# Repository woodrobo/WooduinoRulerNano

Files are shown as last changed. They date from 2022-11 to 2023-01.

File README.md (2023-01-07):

# WooduinoRulerNano
WooduinoRulerNanoは定規風Arduino Nano互換機です。  
定規っぽい見た目なだけでなく、電源電流マシマシに設計していて、3.3Vには800mAの3端子レギュレータを採用していて5Vも配線幅的には2Aほど流せます。Vin端子は使ったこと無かったのでつけていないです。  
[BOOTH](https://woodrobo.booth.pm/items/3751720)で販売しています。

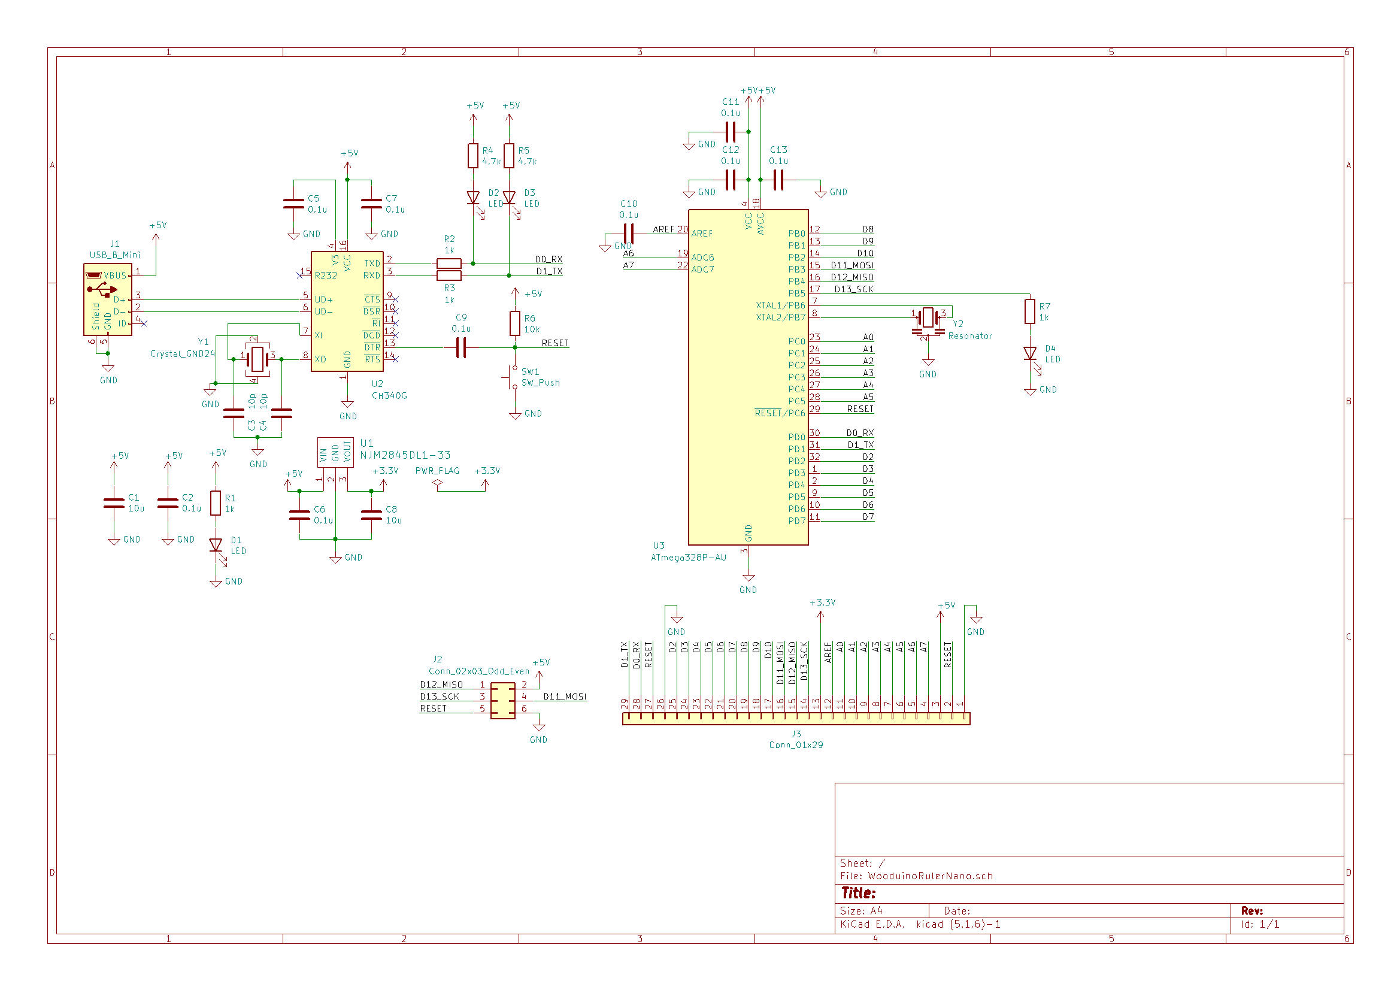
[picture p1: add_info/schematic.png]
  
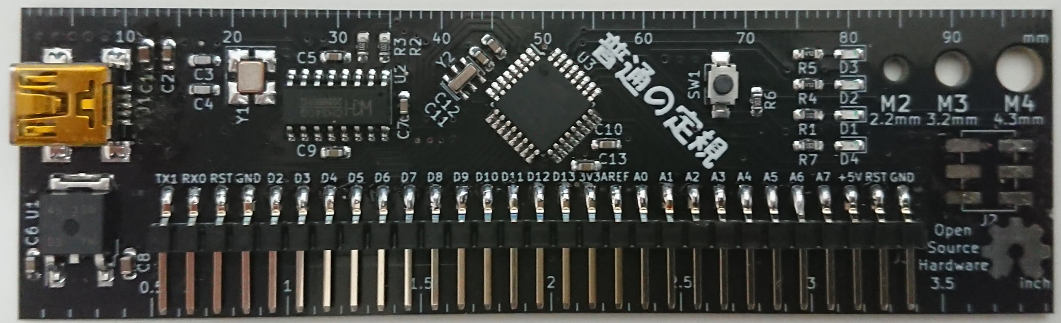
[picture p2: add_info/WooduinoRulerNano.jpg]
基板表面
  
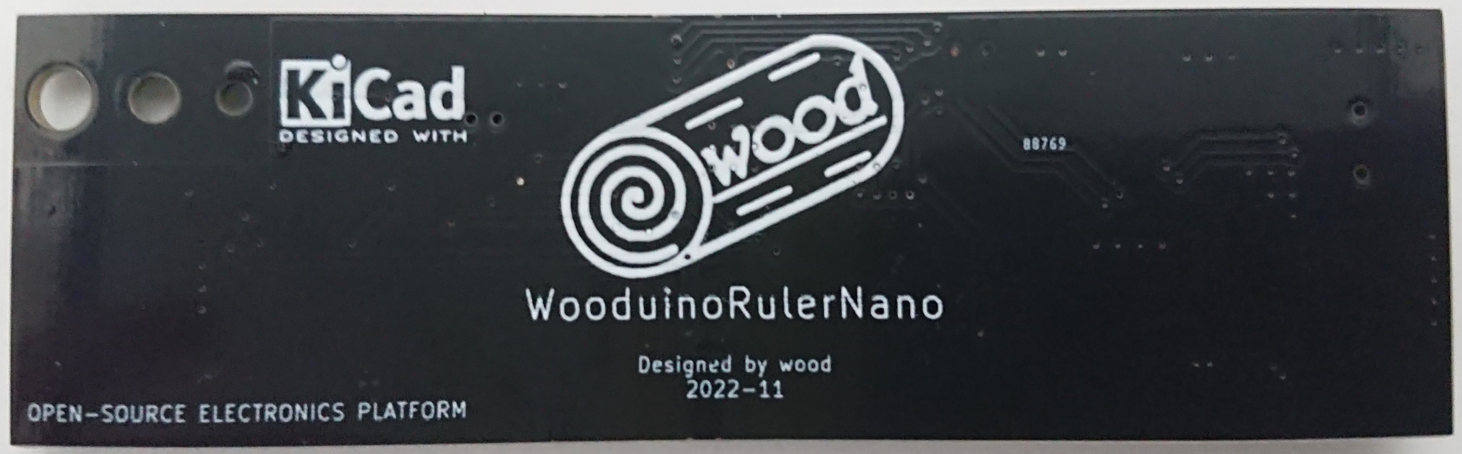
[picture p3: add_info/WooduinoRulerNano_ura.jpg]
基板裏面
  

# 部品・はんだづけについて
add_info/部品表.csvを見てはんだづけを行ってください。  
(ちなみにCH340GではなくCH340Cを使用すればC3,C4,Y1を省略できます)  
向きを間違えやすい4つの箇所を説明します。  

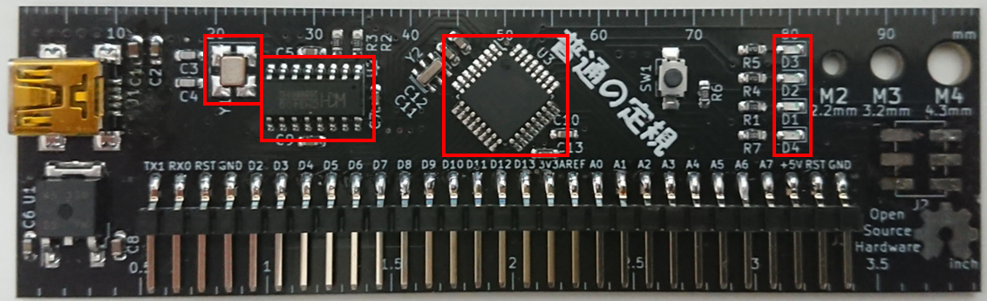
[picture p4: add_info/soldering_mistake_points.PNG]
  

1.クリスタル(12MHz)  
赤枠が1番ピンなので赤枠同士が合うようにしてください。裏面の方が分かりやすいので裏面も写真にのせています。  
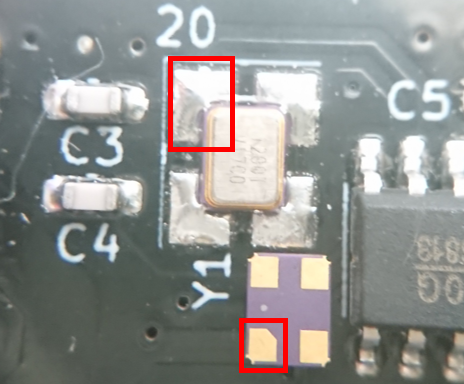
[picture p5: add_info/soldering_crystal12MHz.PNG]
  

2.CH340G  
〇のマークは1番ピンの意味なので、〇のマークに注目して画像と同様の向きにしてください。  
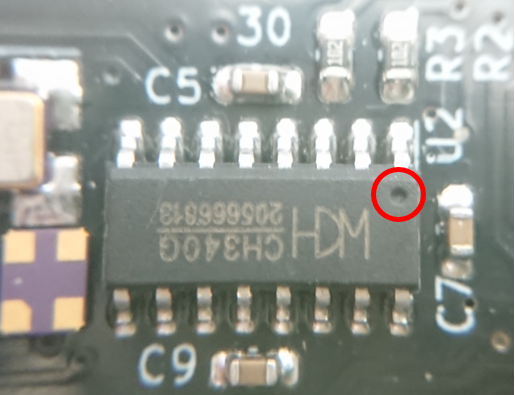
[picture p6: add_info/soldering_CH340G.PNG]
  

3.ATMEGA328P  
〇のマークは1番ピンの意味なので、〇のマークに注目して画像と同様の向きにしてください。  
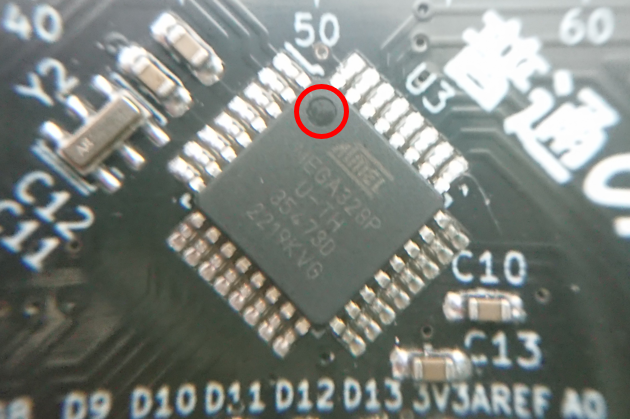
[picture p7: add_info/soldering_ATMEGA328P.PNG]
  

4.LED  
LEDにはアノード・カソードという端子があり極性があります。写真のような向きにしてください。裏面の方が分かりやすいので裏面も写真にのせています。  
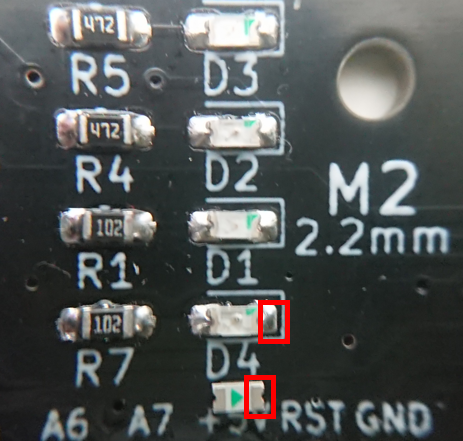
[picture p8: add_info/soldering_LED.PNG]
  

# ブートローダ書き込みについて
Arduinoはブートローダと呼ばれるプログラムを書きこむためのプログラムを書きこむことで動作します。公式の説明は[ここ](https://docs.arduino.cc/built-in-examples/arduino-isp/ArduinoISP)。  
ここではArduino Unoを用いてWooduinoRulerNanoに書きこみを行う方法を説明します。(WooduinoRulerNanoはArduino Nano互換機なのでArduino Nanoについて解説されている他のサイトも参考にしてみてください)  

※Arduino Unoの代わりにArduino Nanoを用いてもやり方は同じです。Arduino UnoのところをArduino Nanoに読み替えてください。 それ以外のArduinoから書き込みを行いたい場合は他のサイトを参照してください。 

**テスト環境**  
ArduinoIDE 1.8.13  
Windows 10

**1.まずはArduino Unoにブートローダ書き込み用のプログラムを書きこみます。**

ファイル->スケッチ例->ArduinoISP->ArduinoISPを開きます。  
Arduino Unoに書きこみます。  

**2.Arduino UnoとWooduinoRulerNanoを結線します。**

書き込みには以下の表に示すように6本の配線が必要です。配線時にはどちらも電源供給は行わないでください。RESETの機能に関しては書き込み機と書き込み対象でピンが違うので注意してください。

|  機能  |  書き込み機(Arduino Uno)  |  WooduinoRulerNano
| ---- | ---- |  ----  |
|  MOSI  |  11  |  11  |
|  MISO  |  12  |  12  |
|  SCK  |  13  |  13  |
|  RESET  |  10  |  RESET  |
|  VCC  |  5V  |  5V  |
|  GND  |  GND  |  GND  |

**3.ブートローダを書きこみます。**

書き込み機であるArduino UnoとパソコンをUSBケーブルで接続してください。(WooduinoRulerNanoへはUSBケーブルを**接続しません**)  

ArduinoIDEにて以下のように設定を行います。

- ツール->ボード->Arduino Nano  
- ツール->プロセッサ->ATmega328P  
- 「ツール->シリアルポート」に書き込み装置のArduino Unoのポートを選択
- ツール->書き込み装置->Arduino as ISP

「ツール->ブートローダを書き込む」でSuccessになれば成功です。

**(4.Lチカのプログラムを書きこんでみましょう。)**  

WooduinoRulerNanoとパソコンをUSBケーブルで接続してください。  

ファイル->スケッチ例->01.Basics->Blinkを開きます。  

- ツール->ボード->Arduino Nano  
- ツール->プロセッサ->ATmega328P 
- 「ツール->シリアルポート」にWooduinoRulerNanoのポートを選択
- ツール->書き込み装置->ArduinoISP

書き込んでLチカができたら成功です。  

# トラブルシューティング
Q.WooduinoRulerNanoのUSBまわりがおかしい  
A.WooduinoRulerNanoのUSBシリアル変換にはCH340を使用しているのでUSBドライバがパソコンにインストールされていない可能性があります。CH340のUSBドライバをパソコンに入れてください。

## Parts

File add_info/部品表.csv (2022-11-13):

Reference | Value | Footprint | 説明
C1 | 10u | Capacitor_SMD:C_0603_1608Metric_Pad1.05x0.95mm_HandSolder | チップコンデンサ10uF
C2 | 0.1u | Capacitor_SMD:C_0603_1608Metric_Pad1.05x0.95mm_HandSolder | チップコンデンサ0.1uF
C3 | 10p | Capacitor_SMD:C_0603_1608Metric_Pad1.05x0.95mm_HandSolder | チップコンデンサ10pF
C4 | 10p | Capacitor_SMD:C_0603_1608Metric_Pad1.05x0.95mm_HandSolder | チップコンデンサ10pF
C5 | 0.1u | Capacitor_SMD:C_0603_1608Metric_Pad1.05x0.95mm_HandSolder | チップコンデンサ0.1uF
C6 | 0.1u | Capacitor_SMD:C_0603_1608Metric_Pad1.05x0.95mm_HandSolder | チップコンデンサ0.1uF
C7 | 0.1u | Capacitor_SMD:C_0603_1608Metric_Pad1.05x0.95mm_HandSolder | チップコンデンサ0.1uF
C8 | 10u | Capacitor_SMD:C_0603_1608Metric_Pad1.05x0.95mm_HandSolder | チップコンデンサ10uF
C9 | 0.1u | Capacitor_SMD:C_0603_1608Metric_Pad1.05x0.95mm_HandSolder | チップコンデンサ0.1uF
C10 | 0.1u | Capacitor_SMD:C_0603_1608Metric_Pad1.05x0.95mm_HandSolder | チップコンデンサ0.1uF
C11 | 0.1u | Capacitor_SMD:C_0603_1608Metric_Pad1.05x0.95mm_HandSolder | チップコンデンサ0.1uF
C12 | 0.1u | Capacitor_SMD:C_0603_1608Metric_Pad1.05x0.95mm_HandSolder | チップコンデンサ0.1uF
C13 | 0.1u | Capacitor_SMD:C_0603_1608Metric_Pad1.05x0.95mm_HandSolder | チップコンデンサ0.1uF
D1 | LED | LED_SMD:LED_0603_1608Metric_Pad1.05x0.95mm_HandSolder | チップLED GREEN
D2 | LED | LED_SMD:LED_0603_1608Metric_Pad1.05x0.95mm_HandSolder | チップLED RED
D3 | LED | LED_SMD:LED_0603_1608Metric_Pad1.05x0.95mm_HandSolder | チップLED GREEN
D4 | LED | LED_SMD:LED_0603_1608Metric_Pad1.05x0.95mm_HandSolder | チップLED YELLOW
J1 | USB_B_Mini | Connector_USB:USB_Mini-B_Wuerth_65100516121_Horizontal | USB miniBコネクタ
J2 | Conn_02x03_Odd_Even | Connector_PinHeader_2.54mm:PinHeader_2x03_P2.54mm_Vertical_SMD | ICSP用PAD はんだづけ非推奨
J3 | Conn_01x29 | 0_kicad_wood:PinHeader_1x29_P2.54mm_Horizontal_SMD_PSL-410256-29 | 表面実装ライトアングルピンヘッダ 1×29
R1 | 1k | Resistor_SMD:R_0603_1608Metric_Pad1.05x0.95mm_HandSolder | チップ抵抗1kΩ
R2 | 1k | Resistor_SMD:R_0603_1608Metric_Pad1.05x0.95mm_HandSolder | チップ抵抗1kΩ
R3 | 1k | Resistor_SMD:R_0603_1608Metric_Pad1.05x0.95mm_HandSolder | チップ抵抗1kΩ
R4 | 4.7k | Resistor_SMD:R_0603_1608Metric_Pad1.05x0.95mm_HandSolder | チップ抵抗4.7kΩ
R5 | 4.7k | Resistor_SMD:R_0603_1608Metric_Pad1.05x0.95mm_HandSolder | チップ抵抗4.7kΩ
R6 | 10k | Resistor_SMD:R_0603_1608Metric_Pad1.05x0.95mm_HandSolder | チップ抵抗10kΩ
R7 | 1k | Resistor_SMD:R_0603_1608Metric_Pad1.05x0.95mm_HandSolder | チップ抵抗1kΩ
SW1 | SW_Push | 0_kicad_wood:SW_TVAF06-A020B-R | 表面実装スイッチ
U1 | NJM2845DL1-33 | Package_TO_SOT_SMD:TO-252-2 | 3端子レギュレータ NJM2845DL1-33
U2 | CH340G | Package_SO:SOIC-16_3.9x9.9mm_P1.27mm | USBシリアル変換 CH340G
U3 | ATmega328P-AU | Package_QFP:TQFP-32_7x7mm_P0.8mm | AVRマイコン ATMEGA328P-AU
Y1 | Crystal_GND24 | Crystal:Crystal_SMD_SeikoEpson_FA238V-4Pin_3.2x2.5mm_HandSoldering | クリスタル12MHz
Y2 | Resonator | Crystal:Resonator_SMD_muRata_CSTxExxV-3Pin_3.0x1.1mm_HandSoldering | セラロック16MHz

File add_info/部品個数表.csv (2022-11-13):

部品名 | 価格 | 個数 | 合計 | URL | 備考
チップコンデンサ10uF | 15 | 2 | 30 | https://akizukidenshi.com/catalog/g/gP-13161/
チップコンデンサ0.1uF | 2.5 | 9 | 22.5 | https://akizukidenshi.com/catalog/g/gP-13374/
チップコンデンサ10pF | 1.8 | 2 | 3.6 | https://akizukidenshi.com/catalog/g/gP-05520/
チップLED GREEN | 12.5 | 2 | 25 | https://akizukidenshi.com/catalog/g/gI-06417/
チップLED RED | 10 | 1 | 10 | https://akizukidenshi.com/catalog/g/gI-03978/
チップLED YELLOW | 10 | 1 | 10 | https://akizukidenshi.com/catalog/g/gI-03984/
USB miniBコネクタ | 50 | 1 | 50 | https://akizukidenshi.com/catalog/g/gC-05843/
ICSP用PAD はんだづけ非推奨 | 0 | 1 | 0 | [参考]https://akizukidenshi.com/catalog/g/gC-06098/
表面実装ライトアングルピンヘッダ 1×29 | 103.4 | 1 | 103.4 | https://www.hirosugi-net.co.jp/shop/g/g24028/ | お好きなコネクタでもﾖｼｯ
チップ抵抗1kΩ | 0.2 | 4 | 0.8 | https://akizukidenshi.com/catalog/g/gR-14122/ | DigiKeyやRS componentsならもっと少ない単位で購入可能
チップ抵抗4.7kΩ | 0.2 | 2 | 0.4 | https://akizukidenshi.com/catalog/g/gR-14121/ | DigiKeyやRS componentsならもっと少ない単位で購入可能
チップ抵抗10kΩ | 0.2 | 1 | 0.2 | https://akizukidenshi.com/catalog/g/gR-15029/ | DigiKeyやRS componentsならもっと少ない単位で購入可能
表面実装スイッチ | 22 | 1 | 22 | https://akizukidenshi.com/catalog/g/gP-14888/
3端子レギュレータ NJM2845DL1-33 | 50 | 1 | 50 | https://akizukidenshi.com/catalog/g/gI-11299/
USBシリアル変換 CH340G | 100 | 1 | 100 | https://akizukidenshi.com/catalog/g/gI-13544/
AVRマイコン ATMEGA328P-AU | 370 | 1 | 370 | https://akizukidenshi.com/catalog/g/gI-04386/
クリスタル12MHz | 50 | 1 | 50 | https://akizukidenshi.com/catalog/g/gP-05225/
セラロック16MHz | 22 | 1 | 22 | https://akizukidenshi.com/catalog/g/gP-14562/
 |  |  | 869.9

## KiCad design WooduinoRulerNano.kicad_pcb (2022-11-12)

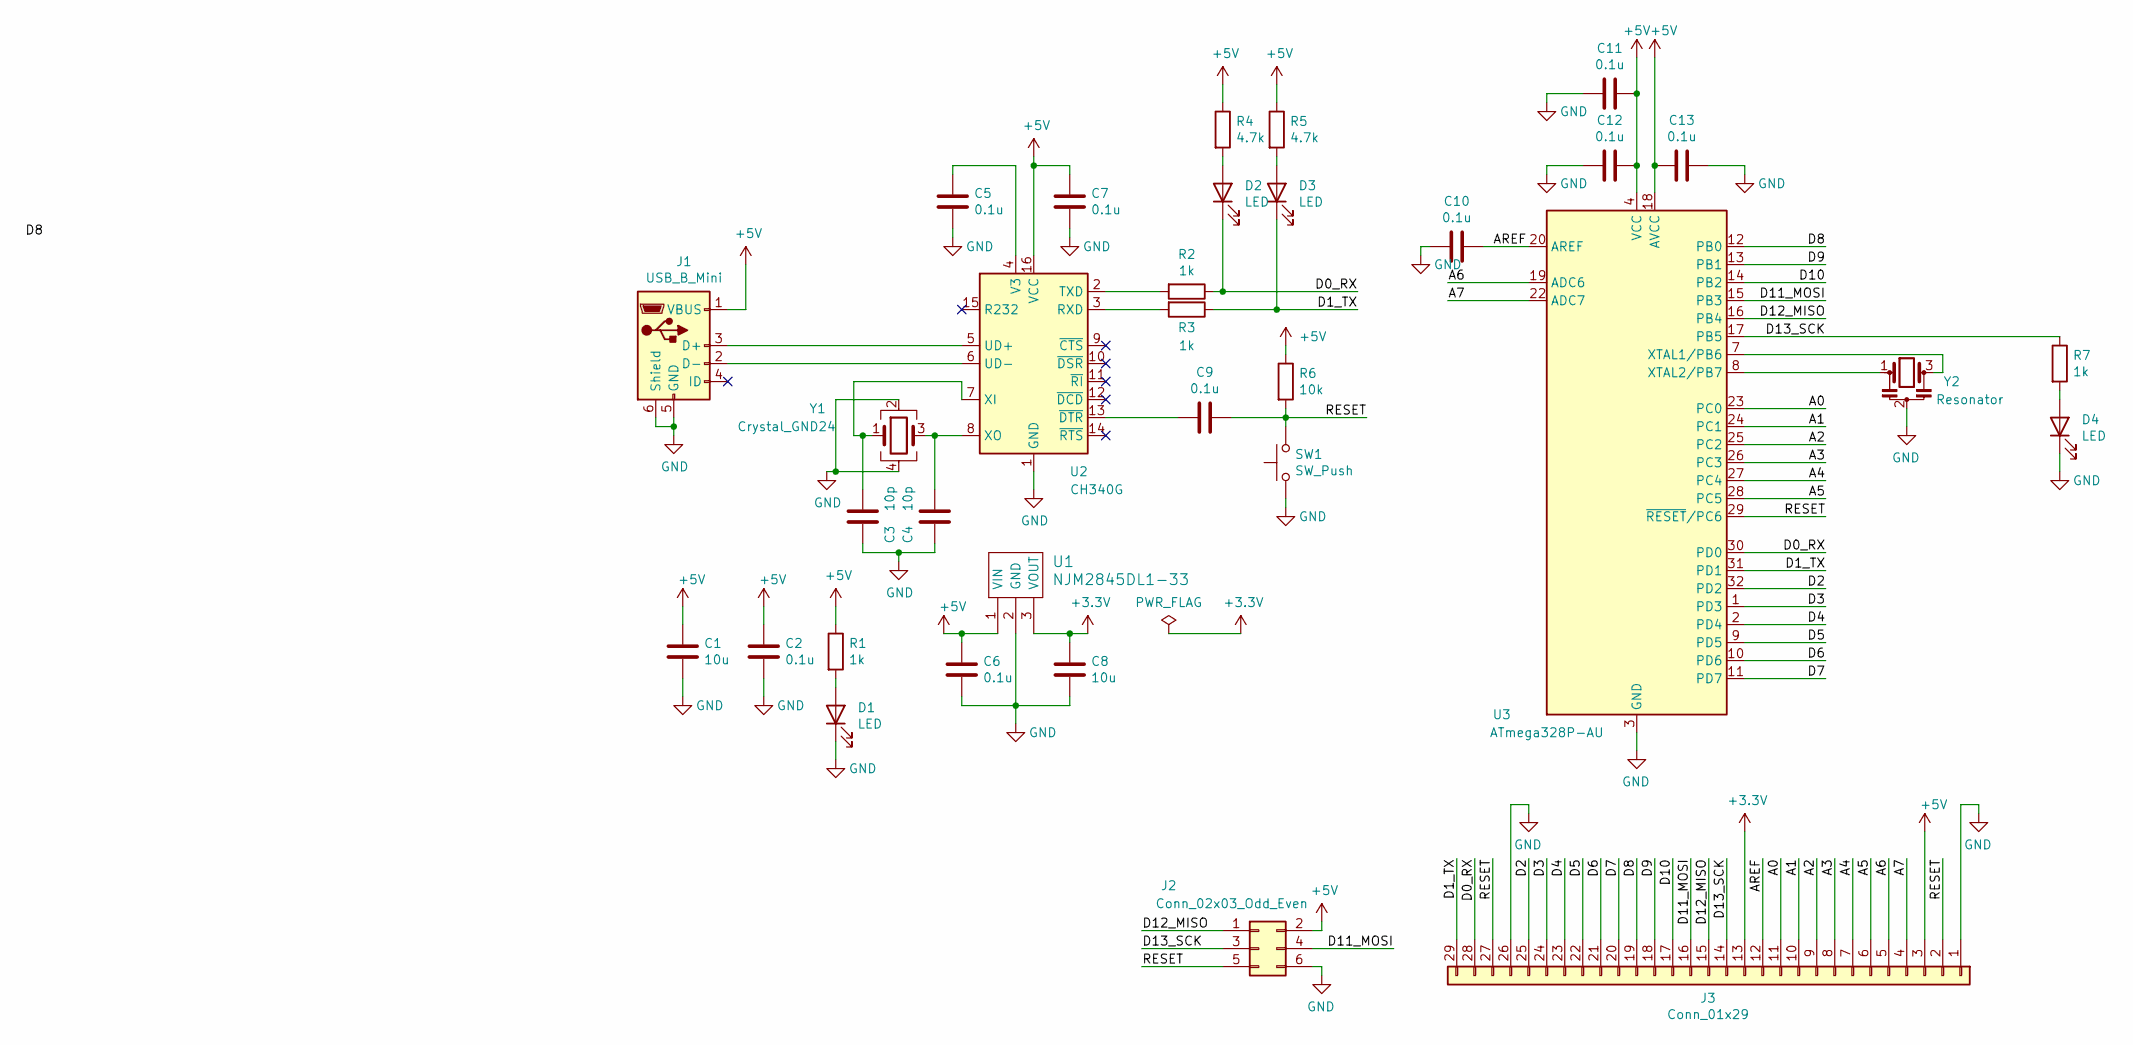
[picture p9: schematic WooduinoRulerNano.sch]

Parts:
C1, C8: 10u; C_0603_1608Metric_Pad1.05x0.95mm_HandSolder
C2, C5, C6, C7, C9, C10, C11, C12, C13: 0.1u; C_0603_1608Metric_Pad1.05x0.95mm_HandSolder
C3, C4: 10p; C_0603_1608Metric_Pad1.05x0.95mm_HandSolder
D1, D2, D3, D4: LED; LED_0603_1608Metric_Pad1.05x0.95mm_HandSolder
J1: USB_B_Mini; USB_Mini-B_Wuerth_65100516121_Horizontal
J2: Conn_02x03_Odd_Even; PinHeader_2x03_P2.54mm_Vertical_SMD
J3: Conn_01x29; PinHeader_1x29_P2.54mm_Horizontal_SMD_PSL-410256-29
R1, R2, R3, R7: 1k; R_0603_1608Metric_Pad1.05x0.95mm_HandSolder
R4, R5: 4.7k; R_0603_1608Metric_Pad1.05x0.95mm_HandSolder
R6: 10k; R_0603_1608Metric_Pad1.05x0.95mm_HandSolder
SW1: SW_Push; SW_TVAF06-A020B-R
U1: NJM2845DL1-33; TO-252-2
U2: CH340G; SOIC-16_3.9x9.9mm_P1.27mm
U3: ATmega328P-AU; TQFP-32_7x7mm_P0.8mm
Y1: Crystal_GND24; Crystal_SMD_SeikoEpson_FA238V-4Pin_3.2x2.5mm_HandSoldering
Y2: Resonator; Resonator_SMD_muRata_CSTxExxV-3Pin_3.0x1.1mm_HandSoldering

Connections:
+3V3: C8.2, J3.13, U1.3 (VOUT)
+5V: C1.2, C2.2, C6.2, C7.1, C11.1, C12.1, C13.2, J1.1 (VBUS), J2.2, J3.3, R1.1, R4.1, R5.1, R6.1, U1.1 (VIN), U2.16 (VCC), U3.4 (VCC), U3.6 (VCC), U3.18 (AVCC)
/A0: J3.11, U3.23 (PC0)
/A1: J3.10, U3.24 (PC1)
/A2: J3.9, U3.25 (PC2)
/A3: J3.8, U3.26 (PC3)
/A4: J3.7, U3.27 (PC4)
/A5: J3.6, U3.28 (PC5)
/A6: J3.5, U3.19 (ADC6)
/A7: J3.4, U3.22 (ADC7)
/AREF: C10.1, J3.12, U3.20 (AREF)
/D0_RX: D2.1 (K), J3.28, R2.1, U3.30 (PD0)
/D1_TX: D3.1 (K), J3.29, R3.1, U3.31 (PD1)
/D2: J3.25, U3.32 (PD2)
/D3: J3.24, U3.1 (PD3)
/D4: J3.23, U3.2 (PD4)
/D5: J3.22, U3.9 (PD5)
/D6: J3.21, U3.10 (PD6)
/D7: J3.20, U3.11 (PD7)
/D8: J3.19, U3.12 (PB0)
/D9: J3.18, U3.13 (PB1)
/D10: J3.17, U3.14 (PB2)
/D11_MOSI: J2.4, J3.16, U3.15 (PB3)
/D12_MISO: J2.1, J3.15, U3.16 (PB4)
/D13_SCK: J2.3, J3.14, R7.1, U3.17 (PB5)
/RESET: C9.1, J2.5, J3.2, J3.27, R6.2, SW1.2, U3.29 (~RESET~/PC6)
GND: C1.1, C2.1, C3.2, C4.1, C5.2, C6.1, C7.2, C8.1, C10.2, C11.2, C12.2, C13.1, D1.1 (K), D4.1 (K), J1.5 (GND), J1.6 (Shield), J2.6, J3.1, J3.26, SW1.1, U1.2 (GND), U2.1 (GND), U3.3 (GND), U3.5 (GND), U3.21 (GND), Y1.2, Y1.4, Y2.2
unnamed: C3.1, U2.7 (XI), Y1.1
unnamed: C4.2, U2.8 (XO), Y1.3
unnamed: C5.1, U2.4 (V3)
unnamed: C9.2, U2.13 (~DTR)
unnamed: D1.2 (A), R1.2
unnamed: D2.2 (A), R4.2
unnamed: D3.2 (A), R5.2
unnamed: D4.2 (A), R7.2
unnamed: J1.2 (D-), U2.6 (UD-)
unnamed: J1.3 (D+), U2.5 (UD+)
unnamed: R2.2, U2.2 (TXD)
unnamed: R3.2, U2.3 (RXD)
unnamed: U3.7 (XTAL1/PB6), Y2.3
unnamed: U3.8 (XTAL2/PB7), Y2.1

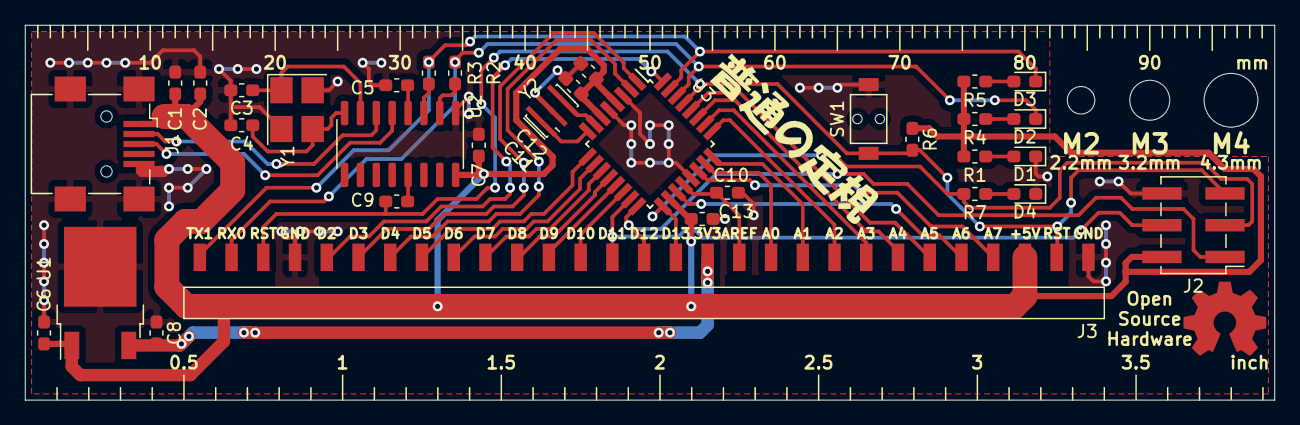
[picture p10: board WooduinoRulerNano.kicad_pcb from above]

Board: 2 copper layers, 100.0 x 30.0 mm, 33 parts (0 on the bottom side), 41 nets.

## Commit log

2022-11-12 設計でけた
    [WooduinoRulerNano.kicad_pcb, WooduinoRulerNano.sch, imposition.kicad_pcb]
2022-11-13 部品表と部品個数表を追加
    [部品個数表.csv, 部品表.csv]
2022-12-22 readme途中まで書いた
2022-12-22 readmeの画像リンクを直した
2022-12-22 readmeの画像リンクをさらに直した
2022-12-22 readmeの改行ミスを直した
2022-12-22 readmeにBoothのURLを追加
2023-01-07 ブートローダの書き込みを追加
